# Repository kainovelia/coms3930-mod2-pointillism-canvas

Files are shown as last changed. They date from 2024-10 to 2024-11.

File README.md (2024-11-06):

# Pointillism Canvas
An interactive dot-based drawing application made with Arduino IDE and Processing

Prototype demo video: [https://drive.google.com/file/d/1kcc5jUUKsq61Xoibje5utA7ILwHvNSOK/view?usp=drive_link](https://drive.google.com/file/d/1kcc5jUUKsq61Xoibje5utA7ILwHvNSOK/view?usp=drive_link)

Sequence 01_1

### Hardware:
- [LilyGo T-Display board](https://www.lilygo.cc/products/lilygo%C2%AE-ttgo-t-display-1-14-inch-lcd-esp32-control-board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) (with headers)
- USB-C cable
- 3 Pushbuttons
- 1 [KY-023 Dual Axis Joystick Module](https://arduinomodules.info/ky-023-joystick-dual-axis-module/)
- 1 RBG LED light
- 1 Precision Potentiometer
- Breadboard
- 5 Male-to-Female Jumper Wires
- As many other types of wires, as needed

### Software:
- [Arduino IDE](https://www.arduino.cc/en/software)
- [Processing](https://processing.org/download) (Sketchbook app) 
- [LilyGo T-Display USB Driver](https://github.com/Xinyuan-LilyGO/TTGO-T-Display)
 
## Setup
- Download the correct driver for the LilyGo T-Display
- Ensure USB-C cable can connect the board and be recognized by Arduino IDE
- Solder the headers into both sides of the board (from beneath, short side up)
- Fit the board headers into the breadboard
- Wire the components as shown in the diagram below
Fritzing Sketch - Pointilism Canvas_bb

## Arduino Program
- Open the file 'mod2-pointillism-canvas.ino'
- Select port connected to wired board
- Click 'Upload'
- Check Serial output in 'Serial Monitor' (most top-right icon)
- Debug wire connections, as needed

## Processing Program
- Once Arduino code properly runs, open the file 'module2_canvas' in Processing
- Click 'Run' and interact with the canvas on screen

## Enclosure Design
- Open the provided STL files in Ultimaker Cura
- Adjust the print settings and send the files over to a compatible 3D printer
- Remove the 3D print and clean up the edges
- Secure the wire connections between the hardware components (by soldering or heatshrink wrapping)
- Add heatsets to the provided holes in each corner of Part 1 and the outside of Part 3
- Attach the hardware components to the outer shell for Part 1. Depending on the type of component, you can glue or securely screw mount them into place
- Snake the wires for each component through their designated holes in Part 2, according to the diagram below. (Below, the joystick mount was not succesfully printed, and the joystick wires were fed through one of the light holes as a result.)
plate wiring
- Additionally, you can organize the bundles and wires by component using scrap pieces of wire, to allow for easier connecting later
- Test the wire connections on the breadboard, following the fritzing diagram above. Adjust and make fixes as necessary.
- Once the wire connections are working, push the Part 2 plate nto the inside of Part 1, as far as it can, to help secure the components.
- Ensure are the wires come out of the opening on the bottom of Part 1. You may want to tape the wires flatly to Part 2, to also help differentiate them by their order.
- Place Part 3 face-down (the side with the Part 2 extrusion) and using M3 10mm screws, screw the enclosure shut by the heatsets in each corner.
- Enclosure is now done, and you can simply connect the wires to the breadboard (with the LilyGo T-Display) when needed to be used.

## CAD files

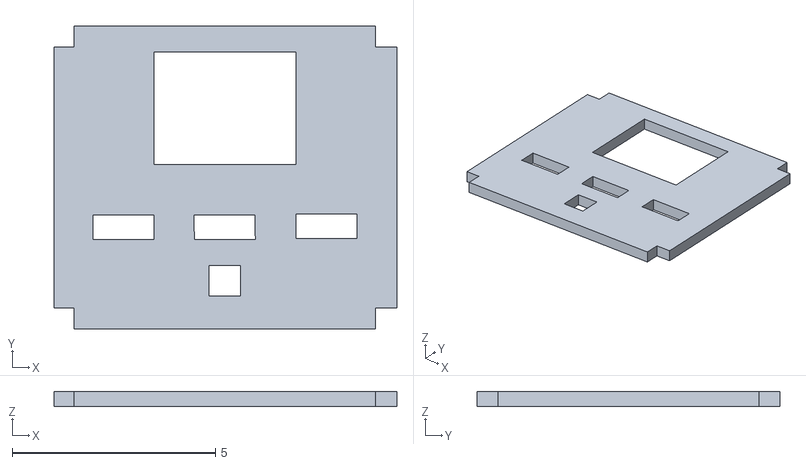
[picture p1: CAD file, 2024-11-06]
Pointillism Canvas STL Files/Pointillism Canvas - Part2.stl
8.44 x 7.45 x 0.38

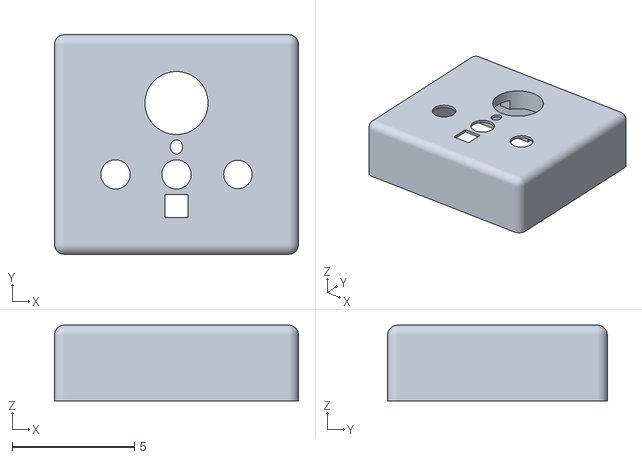
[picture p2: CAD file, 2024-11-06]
Pointillism Canvas STL Files/Pointillism Canvas - Part1.stl
10.0 x 9.00 x 3.10

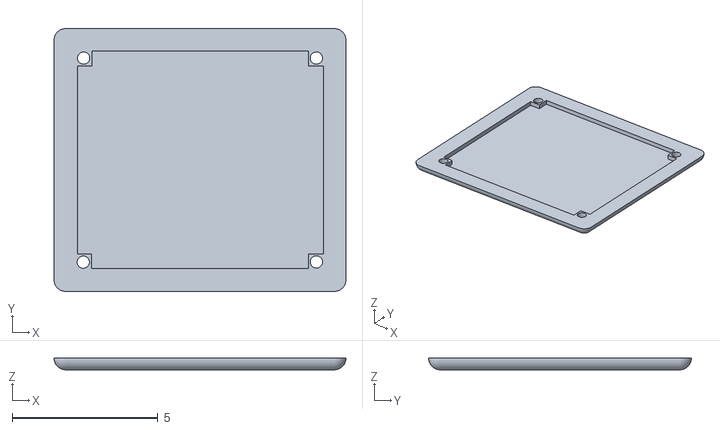
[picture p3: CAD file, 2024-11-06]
Pointillism Canvas STL Files/Pointillism Canvas - Part3.stl
10.0 x 9.00 x 0.4

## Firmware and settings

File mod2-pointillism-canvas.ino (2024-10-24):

/* Pointillism Canvas Arduino Setup
  Karin Novelia - kn2596 
  */


/* Defining input and output pins */
#define RED_LED 12
#define RED_BUTTON 13
#define GREEN_LED 15
#define GREEN_BUTTON 2
#define BLUE_LED 17
#define BLUE_BUTTON 22

#define X_PIN 38
#define Y_PIN 39
#define Z_PIN 32

#define POT_PIN 36

void setup() {
	Serial.begin(115200);

	pinMode(RED_BUTTON, INPUT_PULLUP);
	pinMode(GREEN_BUTTON, INPUT_PULLUP);
	pinMode(BLUE_BUTTON, INPUT_PULLUP);

	pinMode(RED_LED, OUTPUT);
	pinMode(GREEN_LED, OUTPUT);
	pinMode(BLUE_LED, OUTPUT);

  pinMode(Z_PIN, INPUT_PULLUP);
  pinMode(POT_PIN, INPUT_PULLUP);
}
void loop() {
  /* RGB LED state variables */
	int redState = digitalRead(RED_BUTTON);
	int greenState = digitalRead(GREEN_BUTTON);
	int blueState = digitalRead(BLUE_BUTTON);

	if (!redState) {
		digitalWrite(RED_LED, HIGH);
    Serial.printf("1,");
	}	else {
		digitalWrite(RED_LED, LOW);
    Serial.printf("0,");
	}

  if (!greenState) {
		digitalWrite(GREEN_LED, HIGH);
    Serial.printf("1,");
	}	else {
		digitalWrite(GREEN_LED, LOW);
    Serial.printf("0,");
	}

  if (!blueState) {
    digitalWrite(BLUE_LED, HIGH);
    Serial.printf("1,");
  } else {
    digitalWrite(BLUE_LED, LOW);
    Serial.printf("0,");
  }
  /* Joystick input */
  int xVal = analogRead(X_PIN);
  int yVal = analogRead(Y_PIN);
  int zVal = digitalRead(Z_PIN);
  
  /* To see output in Serial Monitor */
  Serial.printf("%d,%d,%d,", xVal, yVal, zVal);
  delay(100);

  /* Potentiometer dial input: range from 0 to 4095 */
  int dialVal = analogRead(POT_PIN);

  Serial.printf("%d", dialVal);
  Serial.println();
  delay(100);

}

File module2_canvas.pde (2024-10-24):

/*
  Module 2 - Pointilism Canvas
  Karin Novelia - kn2596
  */

import processing.serial.*;

Serial myPort;
String input;

int analogMax = 4095;

int circleColor;
int circleSize;

PShape drawn; 

color red = #E03E1B;
color green = #47BD43;
color blue = #0355AE;
color yellow = #FFFC34;
color cyan = #79FFF7;
color purple = #8347ff;
color white = #FFFFFF;
color black = #000000;

void setup() 
{
  /* Window width and height */
  size(2000, 1000);
  
  /* Set up Serial ports */
  /* Uncomment line below to see your port settings */
  // printArray(Serial.list());
  
  /* Replace with board-connected port */
  String port7 = Serial.list()[2];
  
  /* Note: arg3 number must equal baud rate set in Arduino IDE */
  myPort = new Serial (this, port7, 115200);
  
  /* Initializing blank canvas */
  drawn = createShape(GROUP);
  PShape background = createShape(RECT, 0, 0, 2000, 1000);
  drawn.addChild(background);
}

void draw() 
{
  /* Read input from port */
  if ( myPort.available() > 0) {  
    input = myPort.readStringUntil('\n');         
  }
  
  /* Remove any whitespaces  */
  input = trim(input);
  
  /* Process input string */
  if( input != null ) {
    shape(drawn, 0, 0);
    println(input); 
    int[] splitin = int(split(input, ','));
    
    if(splitin.length == 7) {
      int r = splitin[0];
      int g = splitin[1];
      int b = splitin[2];
      
      int x = splitin[3];
      int y = splitin[4];
      int z = splitin[5];
      int d = splitin[6];
    
      /* Dial input -> circle size */
      circleSize = d;
   
       
      /* Button input -> RGB LED */
      if(r == 1 && g == 0 && b == 0){
        circleColor = red;
      } else if (r == 0 && g == 1 && b == 0){
        circleColor = green;
      } else if (r == 0 && g == 0 && b == 1) {
        circleColor = blue;
      } else if (r == 1 && g == 1 && b == 0) {
        circleColor = yellow;
      } else if (r == 1 && g == 0 && b == 1) {
        circleColor = purple;
      } else if (r == 0 && g == 1 && b == 1) {
        circleColor = cyan;
      } else if (r == 1 && g == 1 && b == 1) {
        circleColor = white;
      } else {
        circleColor = black;
      } 
    
      /* Joystick input -> circle cursor position */
      float circleX = map(x, 0, analogMax, 0, 2000);
      float circleY = map(y, 0, analogMax, 0, 1000);
      
      noStroke();
      fill(circleColor);
      circle(circleX, circleY, circleSize);
    
      /* Joystick press -> draw circle to canvas */
      if(z == 0){
        noStroke();
        fill(circleColor);
        PShape dot = createShape(ELLIPSE, circleX, circleY, circleSize, circleSize);
        drawn.addChild(dot);
      }
    }
  }
}   
 
